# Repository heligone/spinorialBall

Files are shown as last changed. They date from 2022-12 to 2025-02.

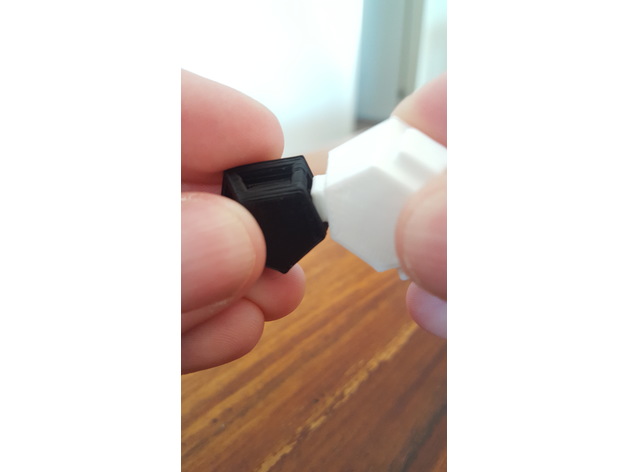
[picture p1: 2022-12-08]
STL/Soccer_ball_Truncated_icosahedron_assembly/images/ee3f00a1cfe0dea914d3099ac7e879d9_preview_featured.jpg

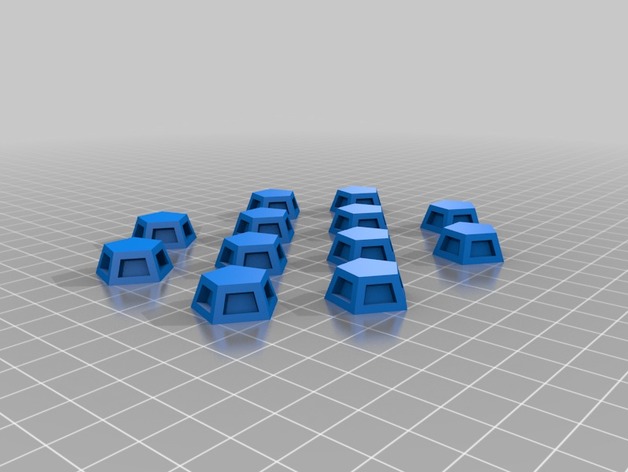
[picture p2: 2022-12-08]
STL/Soccer_ball_Truncated_icosahedron_assembly/images/a9dcccfc0283a2bb433b7402610fc83e_preview_featured.jpg

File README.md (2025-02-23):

# The spinorial ball

A device to visualize 1/2 spin rotations

spinorialBall

## Introduction

The spinorial ball is a LED football containing an electronic 3D gyroscope, powered by an internal battery, whose faces change colors when it is rotated.

You need to turn it twice 360°, so 720°, around any axis so that the configuration gets back to itself.
Turn it once and it becomes the "opposite" of itself (When you consider colors on chromatic wheel) !

The mathematical machinery and physical explanations are detailed in "The spinorial ball: a macroscopic object of spin-1/2".

## Details

It is made of :
- a 3D printed frame divided in two halves of a truncated icosahedron
- 32 addressable multicolor LEDs (WS2812E)
- Arduino compatible Adafruit Feather 32u4 basic proto controller (And an additional featherwing Proto board receiving the LED strip connector)
- Adafruit Bosch BNO055 9 DOF inertial measurement unit
- a 3.7 V 1,1 Wh liPo Battery

openBall (Small)

## Electronics

The controller board is connected to the gyroscope via its 4 pins : 
- Power
- Ground
- SCA pin 3
- SCL pin 2

It is connected to the LED strip via an additional FeatherWing  proto board interface card which holds only a connector for the led strip
- Power
- Ground
- Data pin 12

electronics (Small)

The third board contains only a connector to the LED strip.

electronics assemble (Small)

## Printable frame

It is a truncated icosahedron assembled like a 3D puzzle from 32 hollow pieces : 
- 20 Hexagons
- 12 Pentagons

The geometric 3D print STL files come from https://www.thingiverse.com/thing:2998199

A hole is dug inside each of the 32 pieces to allow for LED placement.

truncatedIcosahedron (Small)

## Usage

Plug the battery.

The gyroscope will calibrate while LEDs are flashing red.

Then the gyroscope will initialize its initial position while LEDs are flashing green.

Then the initial state is displayed : red pentagons, hexagons off.

This correspond to the |up> state.

Close the ball and ... let's play :)

https://user-images.githubusercontent.com/16895004/206660205-fc275f0b-c983-40f3-bc5c-f4d4d745dbe4.mp4

## Online

There is an online version to play with : 

https://dotwave.org/spinorialBall

There is also a smartphone version : 

https://dotwave.org/spinorialPhone

And you can get yourself one ready made :

https://www.spinorialball.com

## License

The Arduino code was written by Samuel BERNARD-BERNARDET and is licensed under the Creative Commons Attribution-NonCommercial 3.0 Unported (CC BY-NC 3.0)

Soccer ball (Truncated icosahedron) assembly by Mattias_Selin is licensed under the Creative Commons - Attribution - Non-Commercial - Share Alike license.

The online version is based on an app by David DUMAS  : https://www.dumas.io/luxball

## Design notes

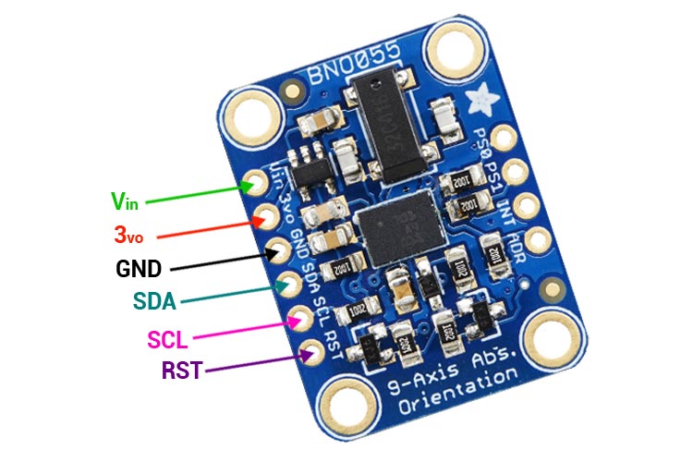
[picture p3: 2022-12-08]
Manufacturer Data Sheets and pinouts/BNO055-Pinout.jpg

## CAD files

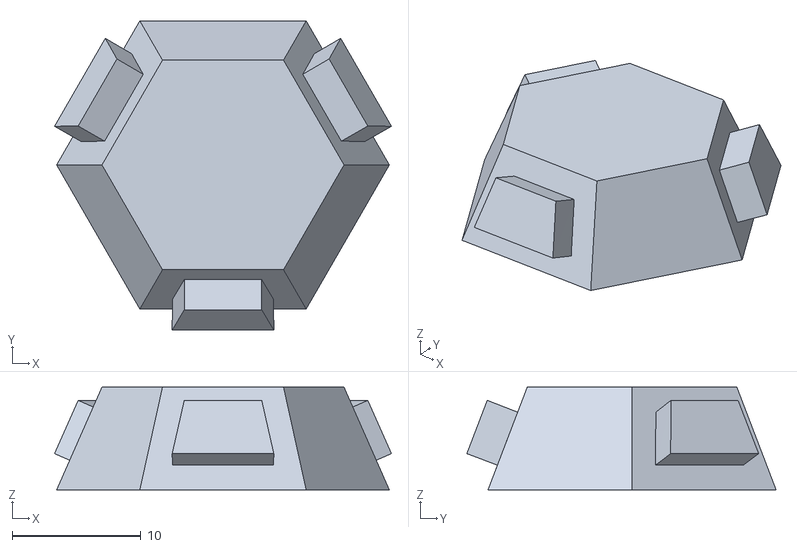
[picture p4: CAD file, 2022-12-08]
STL/Soccer_ball_Truncated_icosahedron_assembly/files/hexagon.stl
26.1 x 24.0 x 7.98

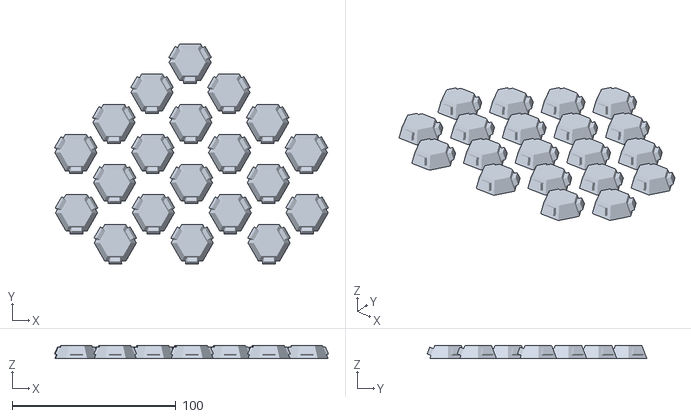
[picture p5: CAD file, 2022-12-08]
STL/Soccer_ball_Truncated_icosahedron_assembly/files/truncated_icosahedron_20_hexagons.stl
167.6 x 134.4 x 7.98

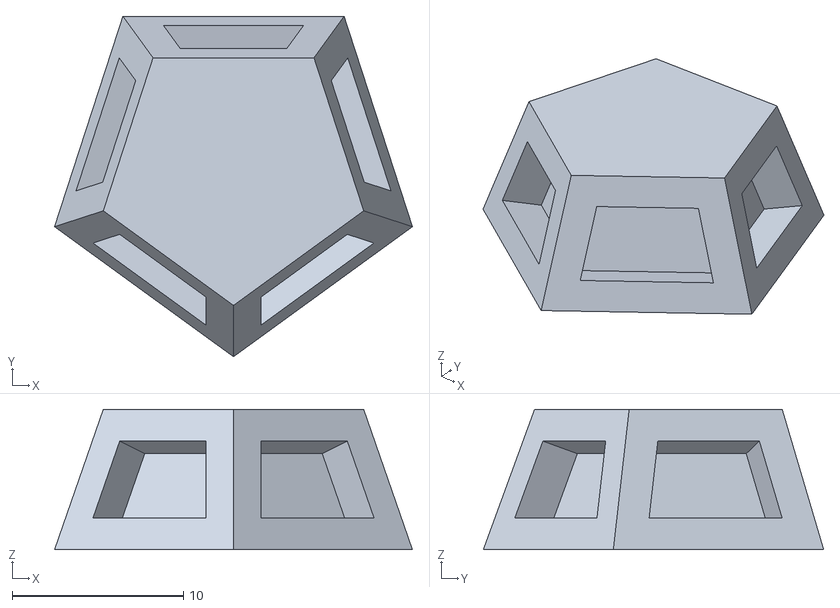
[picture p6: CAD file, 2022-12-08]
STL/Soccer_ball_Truncated_icosahedron_assembly/files/pentagon.stl
20.9 x 19.9 x 8.19

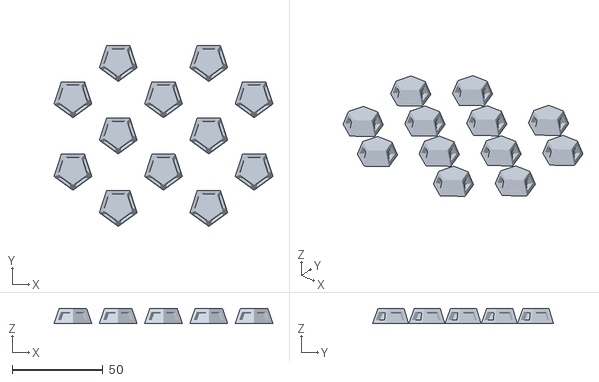
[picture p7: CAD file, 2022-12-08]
STL/Soccer_ball_Truncated_icosahedron_assembly/files/truncated_icosahedron_12_pentagons.stl
120.9 x 99.9 x 8.19

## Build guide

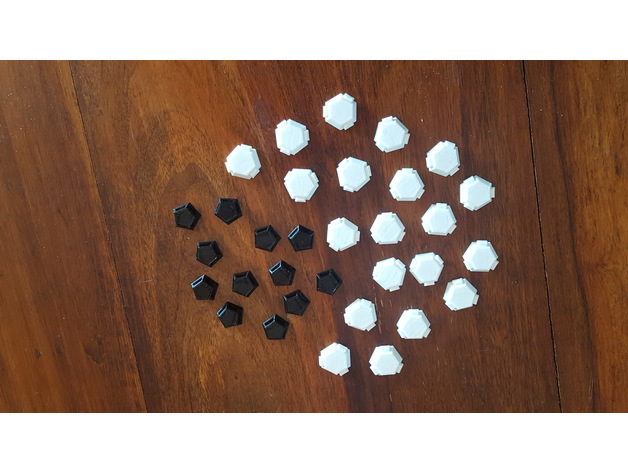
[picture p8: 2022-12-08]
STL/Soccer_ball_Truncated_icosahedron_assembly/images/2f547b9f6f57d549a2a1515ab452c032_preview_featured.jpg

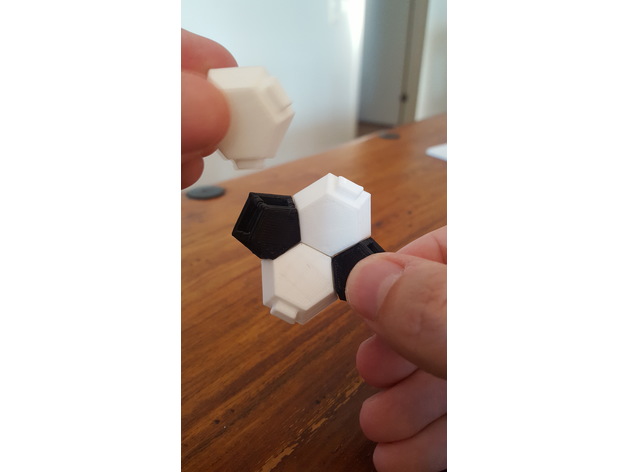
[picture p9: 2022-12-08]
STL/Soccer_ball_Truncated_icosahedron_assembly/images/fc9a0236d4b5a245737000b609531605_preview_featured.jpg

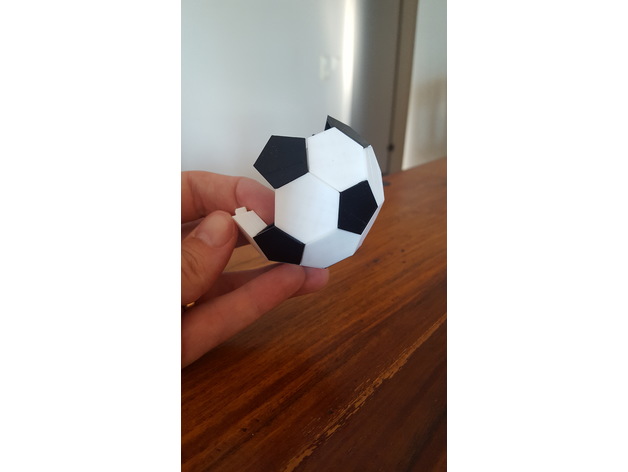
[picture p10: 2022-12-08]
STL/Soccer_ball_Truncated_icosahedron_assembly/images/76725be5572b5d33ae5641d8d75ef75f_preview_featured.jpg

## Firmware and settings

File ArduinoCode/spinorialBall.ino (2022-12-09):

/* Code by Samuel BERNARD-BERNARDET
   www.dotwave.org
 * Licensed under Attribution-NonCommercial 3.0 Unported (CC BY-NC 3.0)

You are free to:
Share — copy and redistribute the material in any medium or format
Adapt — remix, transform, and build upon the material
The licensor cannot revoke these freedoms as long as you follow the license terms.
Under the following terms:
Attribution — You must give appropriate credit, provide a link to the license, and indicate if changes were made. You may do so in any reasonable manner, but not in any way that suggests the licensor endorses you or your use.

NonCommercial — You may not use the material for commercial purposes.

No additional restrictions — You may not apply legal terms or technological measures that legally restrict others from doing anything the license permits.
*/

#include <Adafruit_NeoPixel.h>

#define PIN 12
#define N_LEDS 32

Adafruit_NeoPixel strip = Adafruit_NeoPixel(N_LEDS, PIN, NEO_GRB + NEO_KHZ800);

#include <Wire.h>
#include <Adafruit_Sensor.h>
#include <Adafruit_BNO055.h>
#include <utility/imumaths.h>


/* Adafruit feather 32u4 basic proto 
 * Adafuit BNO055 9DOF Inertial Measurment unit
 * 
 *  Connections
   ===========
   Connect SCL to SCL pin (analog 3 on Arduino Feather 32u4)
   Connect SDA to SDA pin (analog 2 on Arduino Feather 32u4)
   Connect Analog 12 to LED DATA BUS
*/

/* Set the delay between fresh samples */
#define BNO055_SAMPLERATE_DELAY_MS (100)

// Check I2C device address and correct line below (by default address is 0x29 or 0x28)
//                                   id, address
Adafruit_BNO055 bno = Adafruit_BNO055(55, 0x28);

int isCalibrated;
uint8_t system0, gyro0, accel0, mag0;
unsigned long currentTime=0;
unsigned long previousTime=0;

int initTest;
imu::Quaternion quat_i;
imu::Quaternion quat_raw;
imu::Quaternion quat;


/**************************************************************************/
/*
    Arduino setup function (automatically called at startup)
*/
/**************************************************************************/
void setup(void) {
  initTest = 1;
  isCalibrated = 0;

  strip.begin();
  strip.show();  // Initialize all pixels to 'off'

  Serial.begin(115200);
  //Serial.println("Orientation Sensor Test"); Serial.println("");

  if (!bno.begin(  )) {
    /* There was a problem detecting the BNO055 ... check your connections */
    Serial.print("Ooops, no BNO055 detected ... Check your wiring or I2C ADDR!");
    while (1)
      ;
  }

  delay(1000);
}

/**************************************************************************/
/*
    Arduino loop function, called once 'setup' is complete (your own code
    should go here)
*/
/**************************************************************************/
void loop(void) {


  while (isCalibrated == 0) {
      chase(strip.Color(255, 0, 0));
      system0 = gyro0 = accel0 = mag0 = 0;
      bno.getCalibration(&system0, &gyro0, &accel0, &mag0);
         displayCalStatus();

      if (gyro0 == 3 && mag0 >= 0) {
        isCalibrated = 1;
      }
    }

  double gamma;
  double delta;

  if (initTest == 1) {
      for (int i = 0; i <= 31; i++) {
      strip.setPixelColor(i, (0, 255, 0));
      strip.clear();
      //chase(strip.Color(255, 0, 0));
          }
       previousTime=millis();
       currentTime=millis();
       while ((currentTime-previousTime)<5000)
         {
          currentTime=millis();
      chase(strip.Color(0, 255, 0));
        }
            
    /* Get initial sensor event */
    sensors_event_t event0;
    bno.getEvent(&event0);
    quat_i = bno.getQuat();
    initTest = 0;
    delay(BNO055_SAMPLERATE_DELAY_MS);
  }


  /* Get a new sensor event */
  sensors_event_t event;
  bno.getEvent(&event);

  /* Debug info*/
  int8_t mode = bno.Adafruit_BNO055::getMode();

  /* Optional: Display calibration status */
   displayCalStatus();
  // displaySensorStatus();

/* Initialise rotation position*/
  quat_raw = bno.getQuat();
  quat = quat_raw * quat_i.conjugate() * (-1.0);
  quat.normalize();

  double norm_up = sqrt(quat.w() * quat.w() + quat.z() * quat.z());
  double norm_down = sqrt(quat.x() * quat.x() + quat.y() * quat.y());

  // phases entre -pi et pi
  if (norm_up != 0) {
    gamma = acos(quat.y() / norm_up);

  } else {
    gamma = 0;
  }

  if (norm_down != 0) {
    delta = acos(quat.z() / norm_down);
    if (quat.x() > 0) {
      delta = -delta;
    }
  } else {
    delta = 0;
  }

  // entre 0 et 65536
  int gamma2 = (int)((180 * (1 + gamma / PI))) * 65536 / 360;
  int delta2 = (int)((180 * (1 + delta / PI))) * 65536 / 360;

  int sat_up = norm_up * 255;
  int sat_down = norm_down * 255;

  uint32_t rgbcolor1 = strip.gamma32(strip.ColorHSV(gamma2, 255, sat_up));
  uint32_t rgbcolor0 = strip.gamma32(strip.ColorHSV(delta2, 255, sat_down));

/* Set LED colors */
  strip.setPixelColor(0, rgbcolor0);
  strip.setPixelColor(1, rgbcolor1);
  strip.setPixelColor(2, rgbcolor0);
  strip.setPixelColor(3, rgbcolor1);
  strip.setPixelColor(4, rgbcolor0);
  strip.setPixelColor(5, rgbcolor1);
  strip.setPixelColor(6, rgbcolor0);
  strip.setPixelColor(7, rgbcolor0);
  strip.setPixelColor(8, rgbcolor0);
  strip.setPixelColor(9, rgbcolor1);
  strip.setPixelColor(10, rgbcolor0);
  strip.setPixelColor(11, rgbcolor0);
  strip.setPixelColor(12, rgbcolor1);
  strip.setPixelColor(13, rgbcolor0);
  strip.setPixelColor(14, rgbcolor0);
  strip.setPixelColor(15, rgbcolor1);
  strip.setPixelColor(16, rgbcolor0);
  strip.setPixelColor(17, rgbcolor0);
  strip.setPixelColor(18, rgbcolor1);
  strip.setPixelColor(19, rgbcolor0);
  strip.setPixelColor(20, rgbcolor0);
  strip.setPixelColor(21, rgbcolor1);
  strip.setPixelColor(22, rgbcolor0);
  strip.setPixelColor(23, rgbcolor0);
  strip.setPixelColor(24, rgbcolor1);
  strip.setPixelColor(25, rgbcolor0);
  strip.setPixelColor(26, rgbcolor1);
  strip.setPixelColor(27, rgbcolor0);
  strip.setPixelColor(28, rgbcolor1);
  strip.setPixelColor(29, rgbcolor0);
  strip.setPixelColor(30, rgbcolor1);
  strip.setPixelColor(31, rgbcolor0);

  //strip.fill(rgbcolor1);
  strip.show();

  /* Debug Info : Display the quat data */
  Serial.print("Mode");
  Serial.print(mode);
  Serial.print(",");
  Serial.print("qW:");
  Serial.print(quat.w(), 4);
  Serial.print(",");
  Serial.print("qX:");
  Serial.print( quat.x(), 4);
  Serial.print(",");
  Serial.print("qY:");
  Serial.print( quat.y(), 4);
  Serial.print(",");
  Serial.print("qZ:");
  Serial.println(quat.z(), 4);

  /* Optional: Display sensor status (debug only) */
  //displaySensorStatus();
  //Serial.println();

  /* New line for the next sample */
  //Serial.println("");

  /* Wait the specified delay before requesting nex data */
  delay(BNO055_SAMPLERATE_DELAY_MS);
}


/* LED chase Blink */
static void chase(uint32_t c) {
  for (uint16_t i = 0; i < strip.numPixels() + 4; i++) {
    strip.setPixelColor(i, c);      // Draw new pixel
    strip.setPixelColor(i - 4, 0);  // Erase pixel a few steps back
    strip.show();
    delay(10);
  }
}

/* Code below from Adafruit open Source libraies */
/**************************************************************************/
/*
    Displays some basic information on this sensor from the unified
    sensor API sensor_t type (see Adafruit_Sensor for more information)
    
*/
/**************************************************************************/
void displaySensorDetails(void) {
  sensor_t sensor;
  bno.getSensor(&sensor);
  Serial.println("------------------------------------");
  Serial.print("Sensor:       ");
  Serial.println(sensor.name);
  Serial.print("Driver Ver:   ");
  Serial.println(sensor.version);
  Serial.print("Unique ID:    ");
  Serial.println(sensor.sensor_id);
  Serial.print("Max Value:    ");
  Serial.print(sensor.max_value);
  Serial.println(" xxx");
  Serial.print("Min Value:    ");
  Serial.print(sensor.min_value);
  Serial.println(" xxx");
  Serial.print("Resolution:   ");
  Serial.print(sensor.resolution);
  Serial.println(" xxx");
  Serial.println("------------------------------------");
  Serial.println("");
  delay(500);
}

/**************************************************************************/
/*
    Display some basic info about the sensor status
*/
/**************************************************************************/
void displaySensorStatus(void) {
  /* Get the system status values (mostly for debugging purposes) */
  uint8_t system_status, self_test_results, system_error;
  system_status = self_test_results = system_error = 0;
  bno.getSystemStatus(&system_status, &self_test_results, &system_error);

  /* Display the results in the Serial Monitor */
  Serial.println("");
  Serial.print("System Status:0x");
  Serial.println(system_status, HEX);
  Serial.print("Self Test:0x");
  Serial.println(self_test_results, HEX);
  Serial.print("System Error:  0x");
  Serial.println(system_error, HEX);
  Serial.println("");
  delay(500);
}

/**************************************************************************/
/*
    Display sensor calibration status
*/
/**************************************************************************/
void displayCalStatus(void) {
  /* Get the four calibration values (0..3) */
  /* Any sensor data reporting 0 should be ignored, */
  /* 3 means 'fully calibrated" */
  uint8_t system, gyro, accel, mag;
  system = gyro = accel = mag = 0;
  bno.getCalibration(&system, &gyro, &accel, &mag);

  /* The data should be ignored until the system calibration is > 0 */
  Serial.print("\t");
  if (!system) {
    Serial.print("! ");
  }

  /* Display the individual values */
  Serial.print("Sys:");
  Serial.println(system, DEC);
  Serial.print("G:");
  Serial.println(gyro, DEC);
  Serial.print("A:");
  Serial.println(accel, DEC);
  Serial.print("M:");
  Serial.println(mag, DEC);

  
}

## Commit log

2022-12-09 Create license.md
    Attribution-NonCommercial 3.0 Unported (CC BY-NC 3.0)
    This is a human-readable summary of (and not a substitute for) the license. Disclaimer.
    You are free to:
    Share — copy and redistribute the material in any medium or format
    Adapt — remix, transform, and build upon the material
    The licensor cannot revoke these freedoms as long as you follow the license terms.
    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
2025-02-22 Update README.md
    - Fixed "adressable" → "addressable"
    - Fixed "additionnal" → "additional"
    - Fixed "measurment" → "measurement"
    - Fixed "Its is" → "It is"
    - Fixed "via and additional" → "via an additional"
    - Fixed "digged" → "dug"
